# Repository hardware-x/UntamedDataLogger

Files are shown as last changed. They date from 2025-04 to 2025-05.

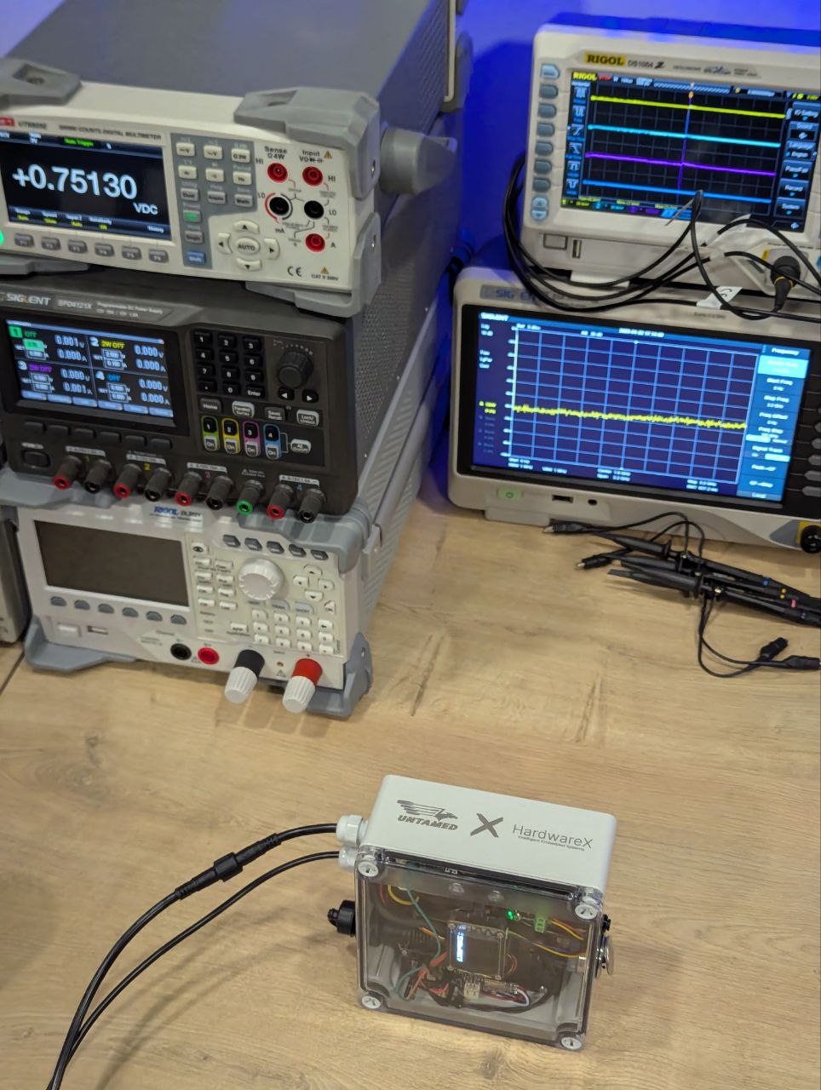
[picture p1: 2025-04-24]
images/photo_2025-04-24_19-03-47.jpg

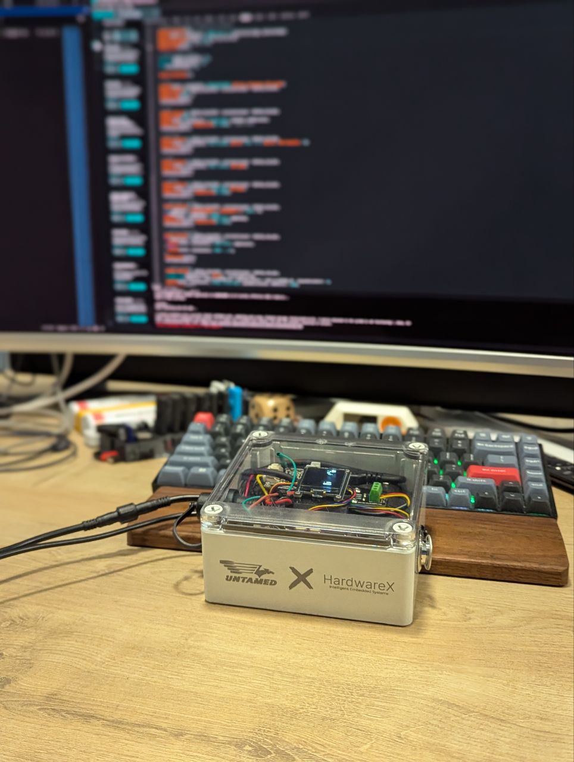
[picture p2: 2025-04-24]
images/photo_2025-04-24_19-03-44.jpg

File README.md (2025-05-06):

# UntamedDataLogger

A robust ESP32-S3-based battery-powered data logging system designed by HardwareX Engineering LTD in collaboration with the UNTAMED team for long-term environmental monitoring. It supports wind speed/direction sensing, GPS tracking, IMU data acquisition, and temperature logging. The system features an OLED interface, onboard SD card logging, and Wi-Fi upload functionality.

---

## 📂 Repository Structure

- **/sourceCode**  
  Contains the full Arduino-based firmware for the ESP32-S3, including sensor drivers, logging routines, Wi-Fi upload, and display rendering logic.

- **/mountingCAD**  
  3D printable and manufacturing-ready enclosure models, mounting inserts, and internal mechanical layout designed for robustness and modular sensor attachment.

- **/images**  
  Reference visuals showing the system’s internal assembly, deployment configuration, live OLED interface, and sensor connectivity.

---

## 🔧 Features

- ESP32-S3 with optimized power draw (~100 mA average)
- GPS (PA1010D) with 6 Hz update rate
- Ultra-low power wind meter (1 Hz)
- 9-DoF IMU (ICM-20948)
- Waterproof DS18B20 temperature sensor
- 1.12" 128x128 OLED display with live stats
- Wi-Fi upload via configurable hotspot
- SD card logging with timestamped CSV entries
- Voltage calibration for precise battery percentage display
- Safe cutoff at 3.60 V for stable operation
- Compatible with 10050 mAh Li-ion batteries
- USB-C port for firmware updates and charging

---

## 🛠️ Getting Started

1. Connect sensors and battery as per provided layout (electronics connection diagram coming soon).
2. Flash the firmware via the **red USB-C** using the `/sourceCode` directory.
3. Power on using the **metal pushbutton**.
4. Ensure Wi-Fi hotspot is named `UNTAMED` with password `UNTAMED4` for upload to function.
5. Monitor real-time readings on the OLED screen.

---

## ⚙️ Calibration & Accuracy

Voltage readings are corrected with a linear mapping based on precision measurements (±0.02 V accuracy). This ensures accurate battery level tracking and protects the system from brownouts.

---

## 📸 Visual Reference

See the `/images` folder for setup examples, internal wiring, and field deployment configurations.

---

## 🔐 License

This project is licensed under the **MIT License**. See the `LICENSE` file for full terms.

---

**P.S.** If you're working on rugged outdoor IoT deployments or need tailored embedded design—feel free to reach out!

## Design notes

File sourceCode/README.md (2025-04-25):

# UNTAMED Embedded Firmware

**Project UNTAMED** is an environmental and motion monitoring system developed by HardwareX Engineering for the "UNTAMED" https://untamed.team/ initiative. This firmware powers the UNTAMED system and orchestrates sensor sampling, data logging, real-time monitoring, and efficient wireless data uplinking — optimized for embedded deployment in harsh and remote environments.

---

## 📦 System Overview

This firmware runs on an **ESP32-S3 Mini** board and manages the following components:

- **ICM-20948 9-DoF IMU** (acceleration, gyro, magnetometer)
- **DS18B20 Waterproof Temperature Sensor**
- **PA1010D GPS Module**
- **ULP Wind Sensor Pro (Ultrasonic)**
- **128x128 SH1107 OLED Display**
- **BQ24074 Power Path Charger (with dynamic system load)**
- **10050 mAh ICR18650 Li-ion battery**

---

## 🚀 Features

- High-resolution data logging with time-synced IMU, GPS, temperature, and wind data
- SD card logging in efficient buffered format
- Automatic log file rotation every 5 minutes
- Display interface showing GPS fix, battery %, system status, wind and motion
- Accurate battery voltage and SoC calculation (with correction and curve-fitting)
- Automatic WiFi-based log upload (when enabled)
- Power optimizations (CPU throttling, radio disablement)
- RTC synchronization via GPS
- Robust boot and I2C handling

---

## 📁 File Structure

| File | Description |
|---|---|
| `UntamedFirmware.ino` | Main firmware entry point |
| `battery.h` | Voltage divider reading, battery % curve, calibration |
| `display.h` | OLED display rendering functions |
| `gps.h` | GPS setup and read logic |
| `logger.h` | Logging to SD, log file management, and formatting |
| `uplink.h` | WiFi data upload routines |
| `globals.cpp` | Global variable definitions and config includes |
| `config.h` | WiFi credentials, timing constants, cloud settings |

---

## 🔋 Battery Monitoring and SoC Estimation

The system reads the battery voltage using a calibrated voltage divider and compensates for ESP32-S3 ADC error. A curve-fitting method maps the measured voltage (after compensation) to real-world battery state-of-charge, based on empirical measurements using precision lab equipment. The system considers 3.60V as the minimum operating threshold.

---

## ⏱ Power Optimization

- Radios disabled when idle (`disableRadios()`)
- CPU frequency scaling supported via `setCpuFrequencyMhz()`
- ADC averaging with calibrated offset and slope correction
- Ultra-lightweight display refresh logic

---

## 📊 Logging Format

Each log file is stored with the following format:
timestamp,type,data...
I: AccelX,AccelY,AccelZ,GyroX,GyroY,GyroZ,MagX,MagY,MagZ
G: Latitude,Longitude,Speed,Course
W: WindSpeed,WindDirection
T: ExternalTempC

Data is flushed every 2 minutes or when buffer is full. Logs are uploaded periodically via WiFi.

---

## 🛠 Build & Flashing

1. Use PlatformIO or Arduino IDE
2. Target Board: `ESP32-S3 Dev Module`
3. Dependencies:
   - `Adafruit_Sensor`
   - `Adafruit_ICM20948`
   - `Adafruit_GFX`, `Adafruit_SH110X`
   - `TinyGPS++`, `OneWire`, `DallasTemperature`
   - `SD`, `WiFi`, `HTTPClient`, `RTClib`

---

## 🧪 Testing Notes

- Verified ADC calibration across voltages 3.4–4.2V
- Real-time graphs generated to validate voltage-to-SoC mapping
- GPS sync verified in both standalone and logged modes
- Tested with Nordic Power Profiler Kit for current draw profiling

---

## 🌐 Server Uploads

The system optionally uploads log snapshots and full logs to a configured backend. It sends full `.log` files using HTTP with custom headers and basic authorization.

---

## 📄 Licensing

This firmware is released under the MIT License.

---

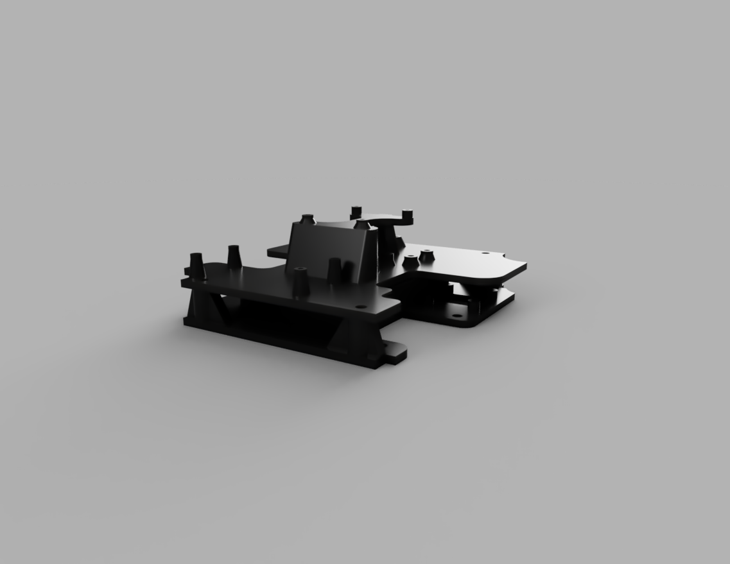
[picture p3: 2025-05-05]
images/3D_SABP131306T_PK2_V1_2025-Apr-28_09-22-58AM-000_CustomizedView9370076511_png.png

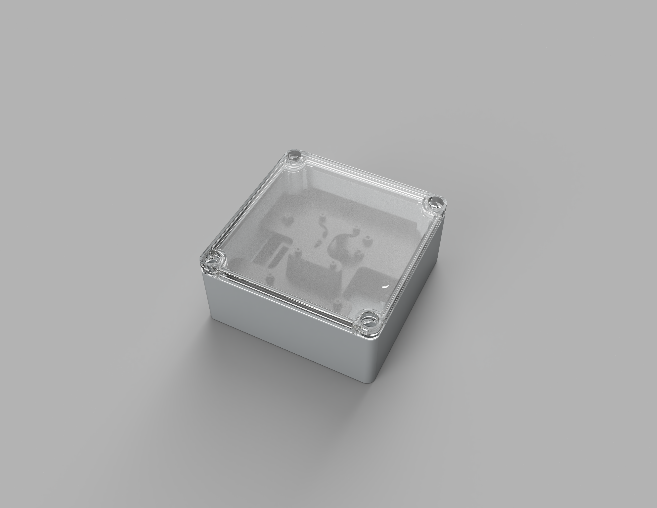
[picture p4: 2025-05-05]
images/3D_SABP131306T_PK2_V1_2025-Apr-14_04-05-35PM-000_CustomizedView20641231281.png

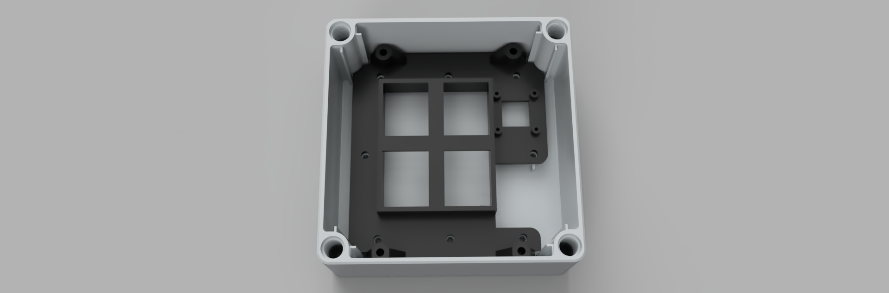
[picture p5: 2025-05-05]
images/3D_SABP131306T_PK2_V1_2025-Apr-28_09-24-28AM-000_CustomizedView21026689896_png.png

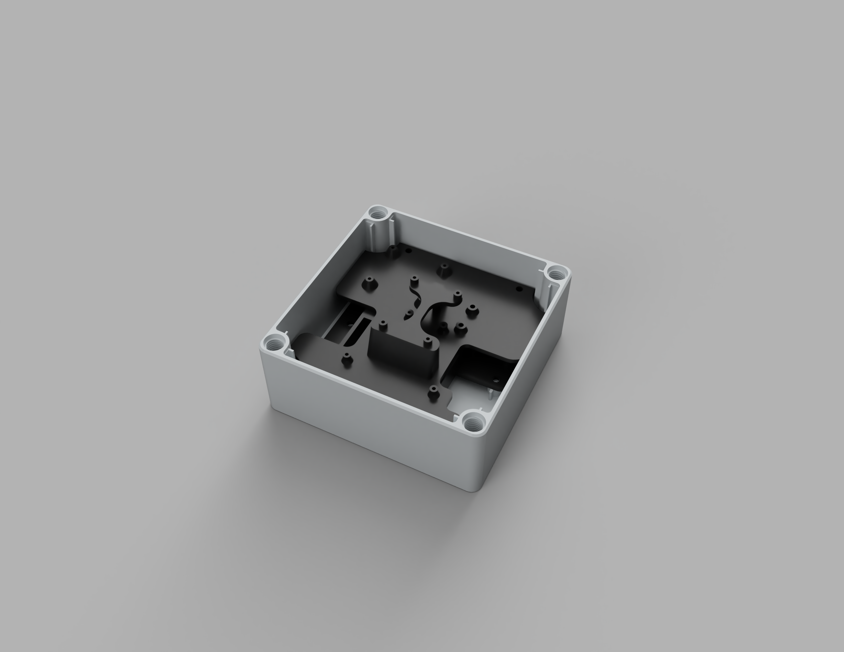
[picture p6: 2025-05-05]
images/3D_SABP131306T_PK2_V1_2025-Apr-14_04-05-48PM-000_CustomizedView20641231281.png

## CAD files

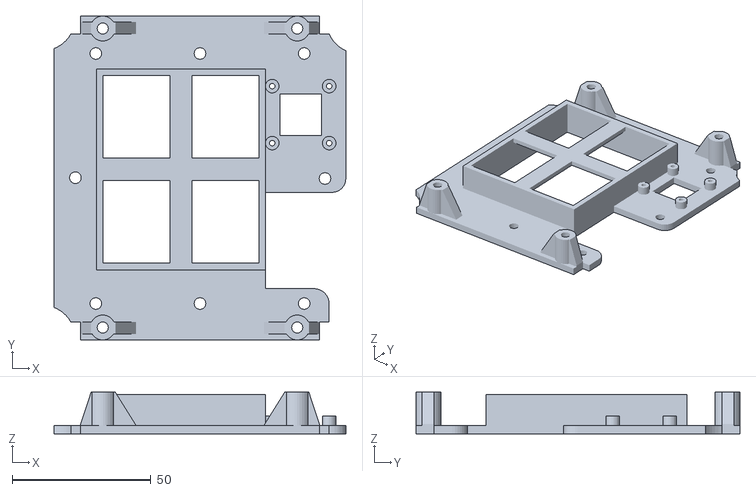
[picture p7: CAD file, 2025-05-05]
mountingCAD/Level 1.stl
105.0 x 116.6 x 15.0

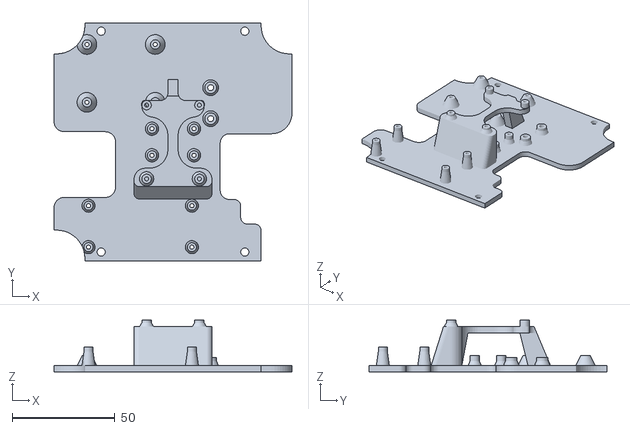
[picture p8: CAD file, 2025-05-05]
mountingCAD/Level 2.stl
116.0 x 116.0 x 25.2

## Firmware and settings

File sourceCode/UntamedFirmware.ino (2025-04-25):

/*
  ------------------------------------------------------------------------------
  UNTAMED DATALOGGER — Firmware v0.4
  ------------------------------------------------------------------------------
  Developed by HardwareX Engineering LTD
  📍 CYENS Centre of Excellence | 🔗 www.hardwarex.cy | ✉️ contact@hardwarex.cy
  ------------------------------------------------------------------------------
  ABOUT HARDWAREX
  HardwareX is a deep-tech R&D firm specializing in custom embedded systems,
  industrial IoT, and TinyML. With proven experience in on-device AI, low-power
  electronics, and advanced manufacturing, we deliver innovative hardware
  tailored for extreme environments and high-impact applications.

  HardwareX leads the development of intelligent, production-ready embedded
  solutions for research, environmental sensing, and industrial systems across
  Europe.

  ------------------------------------------------------------------------------
  PROJECT: UNTAMED — Wind & Motion Environmental Data Logger
  ------------------------------------------------------------------------------
  The UNTAMED logger is a ruggedized, low-power, field-deployable platform
  designed to collect synchronized environmental and motion data using:
    - 9-DoF IMU (ICM-20948)
    - Ultrasonic wind sensor (I2C)
    - DS18B20 temperature probe (1-Wire)
    - GPS positioning (PA1010D)
    - Battery voltage monitor
    - 128x128 OLED Display for field feedback

  Data is stored in SD logs and optionally uploaded via WiFi to a remote
  cloud endpoint. Logging includes timestamps from a real-time clock (DS3231),
  synchronized with GPS when possible.

  ------------------------------------------------------------------------------
  FIRMWARE STRUCTURE
  ------------------------------------------------------------------------------
  • UntamedFirmware.ino  - Main loop and core orchestrator
  • config.h             - Pinouts, intervals, and global constants
  • display.h            - OLED graphics and status display
  • imu.h                - ICM-20948 motion sensor interface
  • temp.h               - DS18B20 temperature sensor logic
  • gps.h                - Adafruit GPS NMEA parsing & RTC sync
  • wind.h               - Ultrasonic wind sensor handler
  • battery.h            - Battery monitoring and percentage calc
  • logger.h             - Sensor data logging, file rotation
  • uplink.h             - WiFi/HTTP data upload routines
  • globals.h            - Definitions of shared global variables

  This modular design ensures clarity, testability, and future scalability.

  ------------------------------------------------------------------------------
*/

#include "config.h"
#include "imu.h"
#include "temp.h"
#include "gps.h"
#include "wind.h"
#include "battery.h"
#include "display.h"
#include "logger.h"
#include "uplink.h"
#include "globals.h"
#include <BDL.h>

BDL dbl;  // Required to call dbl.begin(); — this powers I2C LDO2 rail

void setup() {
  #if DEBUG
  Serial.begin(115200);
  #endif

  setCpuFrequencyMhz(80);  // Lower CPU speed for power saving (options: 240, 160, 80, 40)

  dbl.begin();              // Power up sensors & OLED
  delay(1000);
  Wire.setClock(100000);    // Set I2C speed

  setupDisplay();
  delay(200);               // OLED boot delay
  setupIMU();
  setupGPS();
  setupTempSensor();
  setupWindSensor();
  setupRTC();
  setupLogFile();

  renderIntroDisplay();

  // Initial readings before loop
  readIMU();
  readTempSensor();
  readGPS();
  readWindSensor();
  readBatteryPercentage();

  disableRadios(); // Start in low-power mode
}

unsigned long lastShortRefresh = 0;
unsigned long lastLongRefresh = 0;

void loop() {
  unsigned long now = millis();

  // Refresh GPS, battery, and WiFi upload every 200ms
  if (now - lastShortRefresh >= 200) {
    readGPS();
    lastShortRefresh = now;
  }

  // Refresh display every 950ms
  if (now - lastLongRefresh >= 950) {
    renderDisplay();
    handleWiFiUpload();
    readBatteryPercentage();
    lastLongRefresh = now;
  }

  logAllSensors();
  delay(40);
}

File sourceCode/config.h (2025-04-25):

#ifndef CONFIG_H
#define CONFIG_H

#define DEBUG 0  // Enable (1) or disable (0) serial debug output

#define ONEWIRE_PIN 3  // GPIO pin connected to the DS18B20 1-Wire temperature sensor

#define WIND_SENSOR_I2C_ADDR 0x15  // I2C address of the ULP Wind Sensor PRO
#define WIND_SENSOR_REG_RAW  0x10  // Register to read raw wind speed and direction

#define BATT_PIN 4  // ADC pin connected to the battery voltage divider

#define R1 469700.0  // Resistor R1 (ohms) in battery voltage divider (top)
#define R2 151370.0  // Resistor R2 (ohms) in battery voltage divider (bottom)

#define BATT_READINGS 20  // Number of battery ADC readings to average

#define LOG_BUFFER_SIZE 8192  // Size of log buffer in bytes before flushing to SD

#define IMU_LOG_INTERVAL_MS     100     // Log IMU data every 100ms (10 Hz)
#define WIND_LOG_INTERVAL_MS    1000    // Log wind data every 1000ms (1 Hz)
#define GPS_LOG_INTERVAL_MS     10*1000   // Log GPS data every 10s 
#define TEMP_LOG_INTERVAL_MS    60000   // Log temperature every 60s (1 per minute)
#define LOG_FLUSH_INTERVAL_MS   60000*3   // Flush log buffer to SD every x*m if not full

#define LOG_FILE_DURATION_MINUTES 5  // Duration (in minutes) per log file before rotation

// Wi-Fi transmission interval (just before log file rotation to ensure timely upload)
#define WIFI_TX_INTERVAL_MS (LOG_FILE_DURATION_MINUTES * 60UL * 1000UL - 10000UL)

#define WIFI_SSID "UNTAMED"  // Wi-Fi SSID for data upload
#define WIFI_PASS "UNTAMED4"  // Wi-Fi password for data upload

#define CLOUD_UPLOAD_URL "xxx"  // Endpoint for cloud data upload
#define WIFI_UPLOAD_AUTH "xxx"  // Auth token for cloud uploads

#endif
